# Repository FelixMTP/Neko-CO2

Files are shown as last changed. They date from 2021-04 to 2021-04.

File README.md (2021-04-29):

# Neko+++

Le Neko+++ est un capteur de CO2 avec buzzer et calibration manuelle avec ou sans batterie

auquel j'ai ajouté :
- un buzzer qui sonne un certain nombre de fois.
- une batterie rechargeable
- une fonction de calibration manuelle en extérieur (plus simple) et d’une fonction de calibration manuelle à partir d’un capteur étalonné (plus compliqué)
- trois interrupteurs : pour allumer et éteindre le capteur, pour activer et désactiver le buzzer, pour lancer la calibration

Il est basé sur un mélange :
- du modèle Neko, qui a servi de base : http://lafabrique.centralesupelec.fr/projetco2/#autres
- du modèle Koneko : https://developer.sensirion.com/tutorials/create-your-own-co2-monitor/ et http://lafabrique.centralesupelec.fr/projetco2/#autres
Pour le relevé de mesures du capteur sensirion SCD30, la communication des mesures par Bluetooth et l'application mobile
- du modèle CO2 Ampel : https://github.com/make-IoT/CO2-Ampel/blob/main/CO2-Ampel-DIY-Octopus-SCD30-WEB-AP-CAL.ino
Pour la calibration à une valeur donnée par wifi et la calibration sur l'air extérieur

Fournitures utilisées pour ce modèle (les liens sont indicatifs, les composants identiques ou équivalents peuvent s’acheter ailleurs) :
- 1 Carte ESP32 : https://www.amazon.fr/gp/product/B074RGW2VQ/ (les autres ESP32 sont possible, il faudra juste adapter les paramètres dans l’IDE arduino)
- 2 ou 3 Interrupteurs (2 pour le modèle sans batterie, 3 pour le modèle avec batterie) : https://www.amazon.fr/gp/product/B00O9YQB88/ (d’autres interrupteurs sont possibles aussi mais il faudra peut-être adapter de fichier STL du couvercle)
- 4 Leds : Rouge, jaune, vert, bleu de 20mA
- 4 Résistance 100 ohms
- 1 Capteur : Sensirion SCD30
- 1 Convertisseur d’alimentation (seulement pour le modèle avec batterie) : https://www.amazon.fr/gp/product/B07MY3NZ18
- 1 Module de charge de batterie 18650 (seulement pour le modèle avec batterie) : https://www.amazon.fr/gp/product/B0798M12N8
- 1 Batterie 18650 (seulement pour le modèle avec batterie) : https://www.amazon.fr/gp/product/B08CC5P4HN/
- 1 Support pour batterie (seulement pour le modèle avec batterie) : https://www.amazon.fr/gp/product/B08CY56M98/

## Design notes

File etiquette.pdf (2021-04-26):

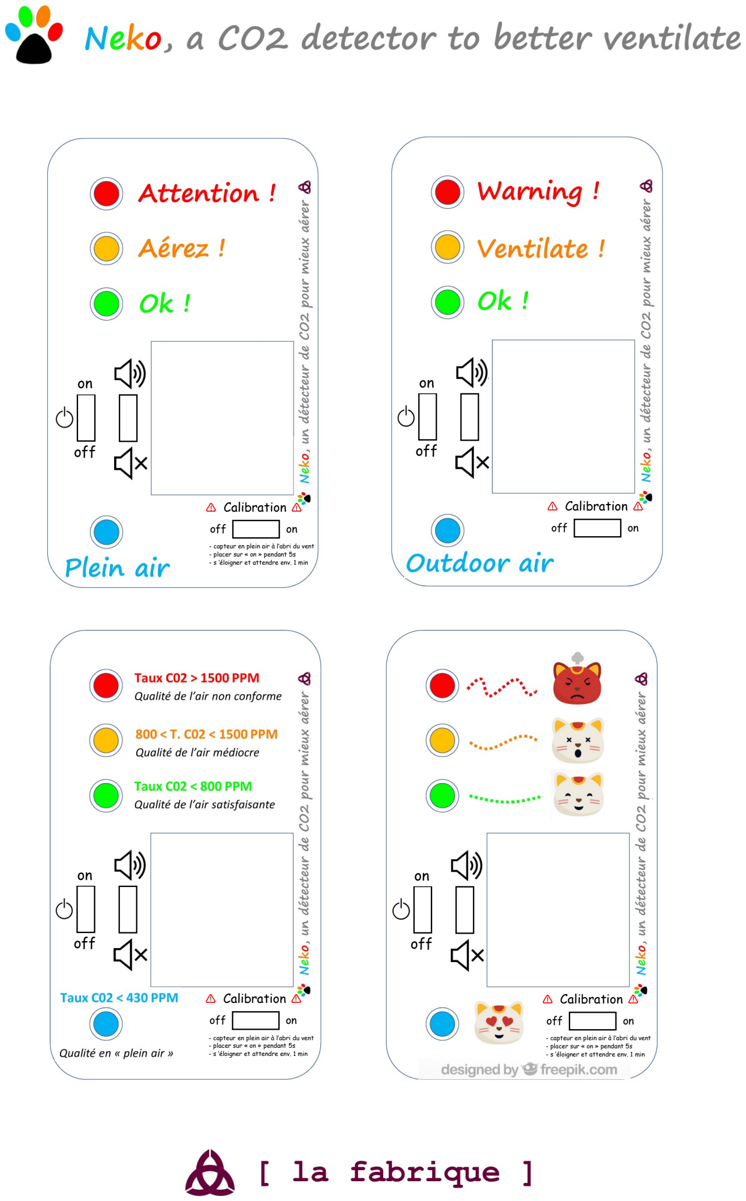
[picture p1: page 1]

# off

on

off | on
- capteur en plein air à l’abri du vent
- placer sur « on » pendant 5s
- s ‘éloigner et attendre env. 1 min

# ! Calibration !

# off

on

off | on
- capteur en plein air à l’abri du vent
- placer sur « on » pendant 5s
- s ‘éloigner et attendre env. 1 min

# ! Calibration !

# off

on

off | on
! | Calibration !

# off

on

off | on
- capteur en plein air à l’abri du vent
- placer sur « on » pendant 5s
- s ‘éloigner et attendre env. 1 min
! | Calibration | !

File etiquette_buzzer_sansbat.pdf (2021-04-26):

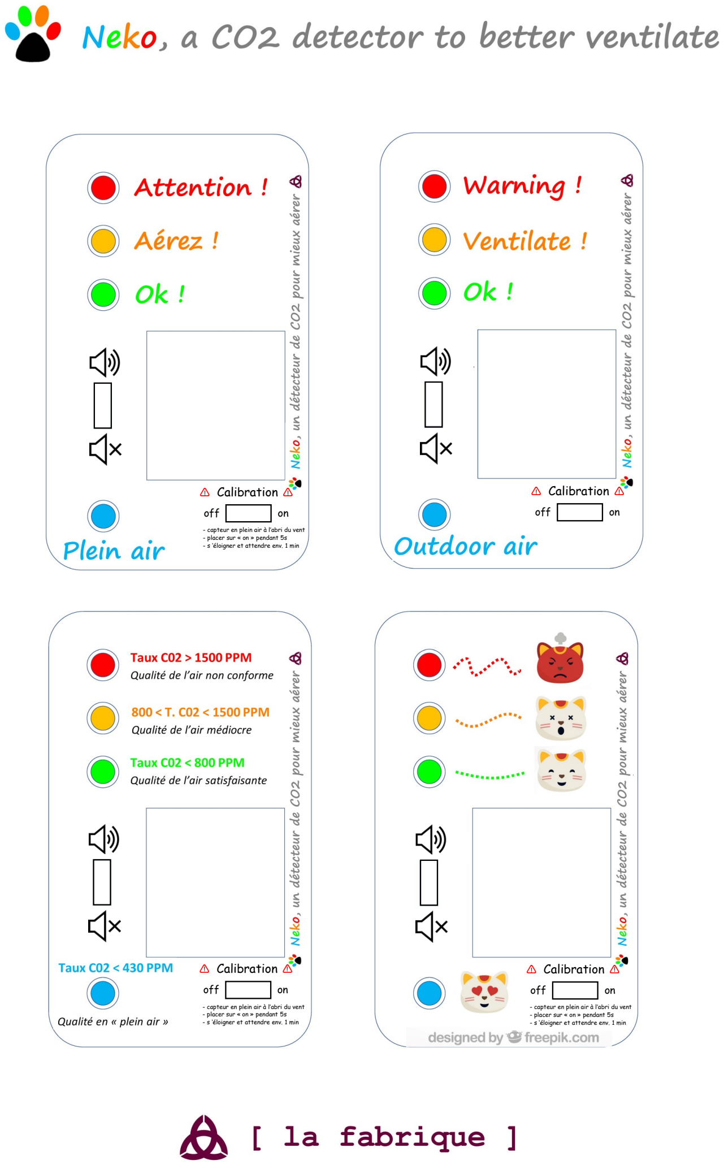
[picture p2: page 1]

off | on
- capteur en plein air à l’abri du vent
- placer sur « on » pendant 5s
- s ‘éloigner et attendre env. 1 min
! | Calibration !
off | on
- capteur en plein air à l’abri du vent
- placer sur « on » pendant 5s
- s ‘éloigner et attendre env. 1 min
! | Calibration !
off | on
! | Calibration !
off | on
- capteur en plein air à l’abri du vent
- placer sur « on » pendant 5s
- s ‘éloigner et attendre env. | 1 min
! | Calibration | !

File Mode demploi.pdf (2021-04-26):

# Capteur de CO2 Neko+++

Le taux de CO2 en extérieur est d’environ 400 ppm.
La mesure du taux de CO2 dans les lieux clos donne ainsi une indication de la quantité d’air qui a été expiré par les personnes présentes dans la pièce, donc une indication de la concentration en aérosols et du risque de transmission du Covid dans ce lieu.
Pour être utilisé, ce capteur doit être calibré à partir de l’air extérieur. Cette calibration peut être renouvelée régulièrement.

### 1) Calibration simple :

Précautions : éviter la calibration lorsqu’il y a beaucoup de vent car le vent perturbe la mesure donc la calibration. Si nécessaire, placer le capteur à l’abri entre des objets ou une boite mais ne pas la fermer complètement.
Þ Placer le capteur en extérieur, loin de tout source de CO2 (donc loin d’une fenêtre, d’une évacuation d’air, d’une cheminée, d’animaux ou de personnes, etc) pendant quelques minutes
Þ Positionner le bouton de calibration sur ON jusqu’à ce que les LED de couleur s’éteignent puis repositionnez le bouton de calibration sur OFF et s’éloigner rapidement de plusieurs mètres
Þ Laisser le capteur effectuer sa calibration jusqu’à ce que l’une des LED (normalement la bleue) se rallume. Cette opération peut prendre plusieurs minutes.
Après quelques temps d’utilisation en intérieur, il est conseillé de tester régulièrement la calibration en plaçant le capteur en extérieur et vérifier que la moyenne des mesures se situe autour de 400 ppm.

### 2) Utilisation:

Þ Placer le capteur dans la pièce à mi-hauteur. Il ne doit pas être placé à coté d’une fenêtre, ni juste à côté d’une personne car cela fausserait les mesures.
Þ | Positionner le bouton | sur ON
Þ | Positionner le bouton du buzzer : | si le buzzer doit sonner lorsque le taux devient supérieur à 1500 ppm ou | s’il ne doit pas sonner.

### 3) Mesure :

Þ Mesure simple : Les LEDS s’allument en fonction du taux de CO2 mesuré.
- Led bleue : le lieu est très bien ventilé car la qualité de l’air est semblable à l’air extérieur
- Led verte : Le lieu est correctement ventilé
- Led orange/jaune : Le lieu n’est pas assez ventilé, il faudrait donc ouvrir (ou ouvrir davantage) les fenêtres.
- Led rouge : le lieu n’est pas ou trop peu ventilé et la qualité de l’air n’est pas conforme, il faut ouvrir les fenêtres.

Þ Mesure chiffrée :
Si vous souhaitez obtenir le taux de CO2 mesuré par le capteur, vous pouvez installer l’application
mobile Sensirion MyAmbience à partir du QR-Code ou les liens suivants :
- Pour Android : https://play.google.com/store/apps/details?id=com.sensirion.myam
- Pour iOS : https://apps.apple.com/ch/app/sensirion-myambience-co2/id1529131572 N’oubliez pas d’activer le Bluetooth de votre appareil.
Une fois installée, l’application se connecte au capteur par Bluetooth et affiche :

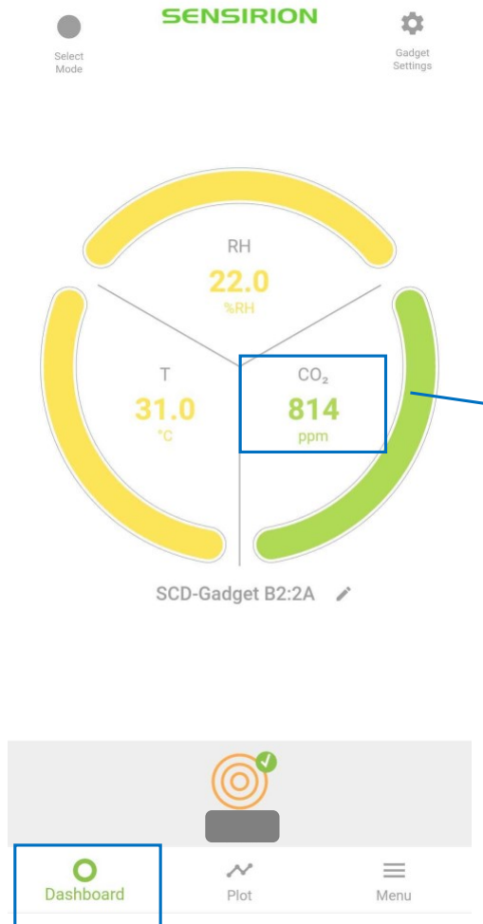
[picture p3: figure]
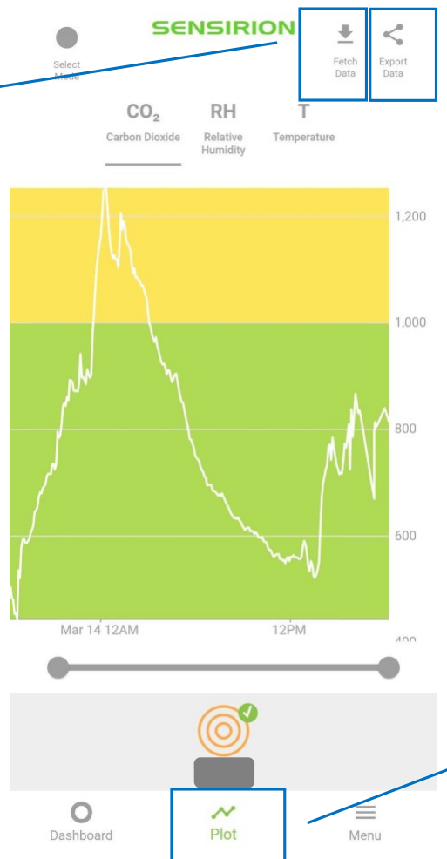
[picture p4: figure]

Taux de CO2.
Attention, les plages de
couleurs dans l’appli ne
correspondent pas aux plages de couleurs pour limiter les risques de transmission du covid

Onglet Dashboard :
Affiche la mesure
instantanée

Exporter les données :
Permet de récupérer les
mesures dans un tableau qui peut s’ouvrir avec un tableur

Onglet Plot :
Affiche la courbe des mesures. Attention, pour que la courbe soit complète, il faut télécharger les données du capteur

Acquérir les données :
Permet de récupérer les
mesures du capteur pour que le graphique soit complet. Attention : ça prend très
longtemps !
Android : | Apple :

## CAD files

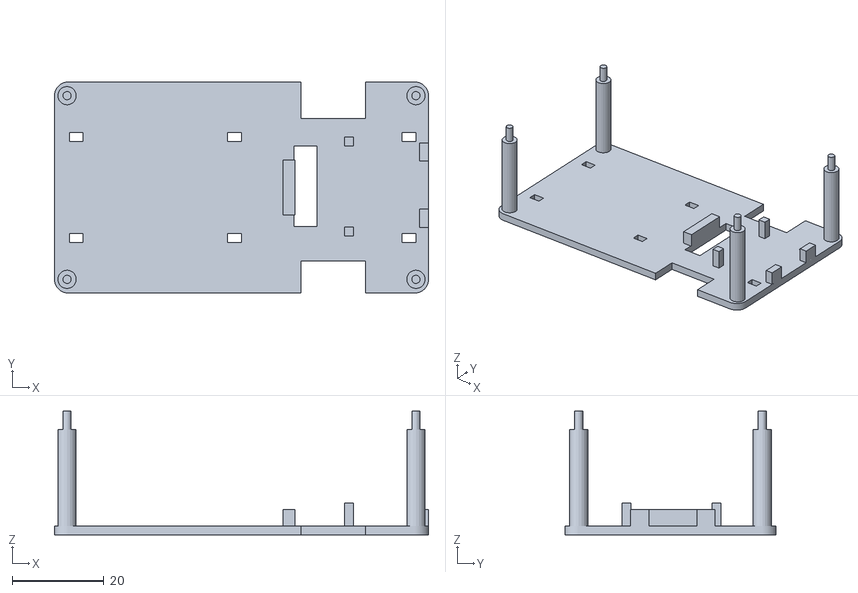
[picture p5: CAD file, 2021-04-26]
Boitier/PCB2.stl
81.5 x 46.0 x 27.0

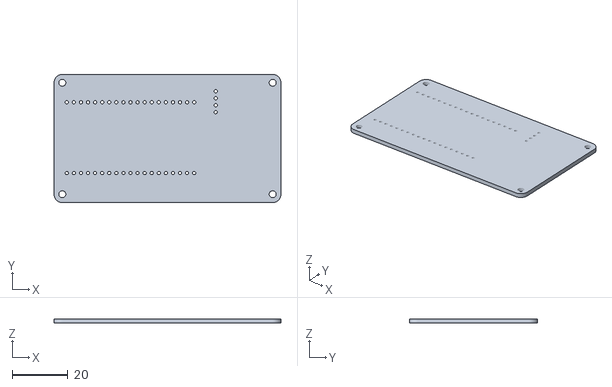
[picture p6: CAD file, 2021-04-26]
Boitier/PCB1.stl
81.5 x 46.0 x 1.60

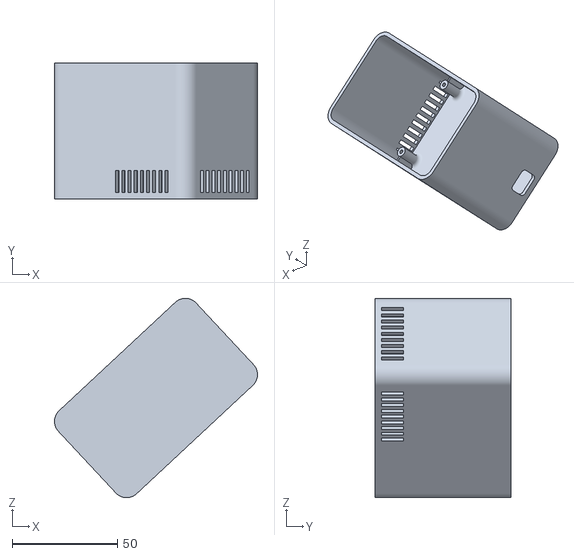
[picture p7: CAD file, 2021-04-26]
Boitier/boitier_sans_batterie.stl
96.5 x 64.6 x 94.7

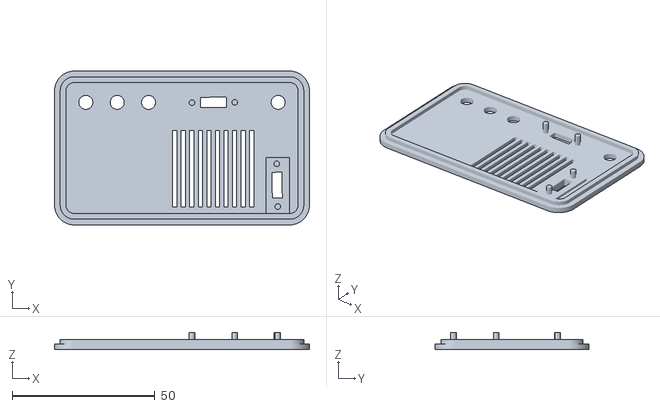
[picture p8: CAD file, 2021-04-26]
Boitier/facade_2boutons.stl
89.5 x 54.0 x 6.00

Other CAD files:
Boitier/boitier_batterie.stl
Boitier/facade_3boutons.stl

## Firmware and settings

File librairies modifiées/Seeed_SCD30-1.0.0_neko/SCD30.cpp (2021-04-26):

/*
    A library for Grove -

    Copyright (c) 2018 seeed technology co., ltd.
    Author      : Wayen Weng
    Create Time : November 2018
    Change Log  :

    The MIT License (MIT)

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
    THE SOFTWARE IS PROVIDED "AS IS", WITHOUT WARRANTY OF ANY KIND, EXPRESS OR
    IMPLIED, INCLUDING BUT NOT LIMITED TO THE WARRANTIES OF MERCHANTABILITY,
    FITNESS FOR A PARTICULAR PURPOSE AND NONINFRINGEMENT. IN NO EVENT SHALL THE
    AUTHORS OR COPYRIGHT HOLDERS BE LIABLE FOR ANY CLAIM, DAMAGES OR OTHER
    LIABILITY, WHETHER IN AN ACTION OF CONTRACT, TORT OR OTHERWISE, ARISING FROM,
    OUT OF OR IN CONNECTION WITH THE SOFTWARE OR THE USE OR OTHER DEALINGS IN
    THE SOFTWARE.
*/

#include "SCD30.h"

SCD30::SCD30(void) {
    devAddr = SCD30_I2C_ADDRESS;
}

void SCD30::initialize(void) {
    //Set temperature offset。
    //setTemperatureOffset(0);

    setMeasurementInterval(2); // 2 seconds between measurements
    startPeriodicMeasurment(); // start periodic measuments

    //setAutoSelfCalibration(true); // Enable auto-self-calibration
}


void SCD30::setTemperatureOffset(uint16_t offset) {
    writeCommandWithArguments(SCD30_SET_TEMP_OFFSET, offset);
}

bool SCD30::isAvailable(void) {
    return readRegister(SCD30_GET_DATA_READY);
}

void SCD30::setAutoSelfCalibration(bool enable) {
    if (enable) {
        writeCommandWithArguments(SCD30_AUTOMATIC_SELF_CALIBRATION, 1);    //Activate continuous ASC
    } else {
        writeCommandWithArguments(SCD30_AUTOMATIC_SELF_CALIBRATION, 0);    //Deactivate continuous ASC
    }
}

//Set the forced recalibration factor. See 1.3.7.
//The reference CO2 concentration has to be within the range 400 ppm ≤ cref(CO2) ≤ 2000 ppm.
void SCD30::setForcedRecalibrationFactor(uint16_t concentration)
{
  if (concentration > 400 || concentration < 2000)
	writeCommandWithArguments(SCD30_SET_FORCED_RECALIBRATION_FACTOR, concentration);
  }

void SCD30::setMeasurementInterval(uint16_t interval) {
    writeCommandWithArguments(SCD30_SET_MEASUREMENT_INTERVAL, interval);
}

void SCD30::startPeriodicMeasurment(void) {
    writeCommandWithArguments(SCD30_CONTINUOUS_MEASUREMENT, 0x0000);
}

void SCD30::stopMeasurement(void) {
    writeCommand(SCD30_STOP_MEASUREMENT);
}

void SCD30::getCarbonDioxideConcentration(float* result) {
    uint8_t buf[18] = { 0 };
    uint32_t co2U32 = 0;
    uint32_t tempU32 = 0;
    uint32_t humU32 = 0;
    float co2Concentration = 0;
    float temperature = 0;
    float humidity = 0;

    writeCommand(SCD30_READ_MEASUREMENT);
    readBuffer(buf, 18);

    co2U32 = (uint32_t)((((uint32_t)buf[0]) << 24) | (((uint32_t)buf[1]) << 16) |
                        (((uint32_t)buf[3]) << 8) | ((uint32_t)buf[4]));

    tempU32 = (uint32_t)((((uint32_t)buf[6]) << 24) | (((uint32_t)buf[7]) << 16) |
                         (((uint32_t)buf[9]) << 8) | ((uint32_t)buf[10]));

    humU32 = (uint32_t)((((uint32_t)buf[12]) << 24) | (((uint32_t)buf[13]) << 16) |
                        (((uint32_t)buf[15]) << 8) | ((uint32_t)buf[16]));

    memcpy(&result[0], &co2U32, sizeof(co2Concentration));
    memcpy(&result[1], &tempU32, sizeof(temperature));
    memcpy(&result[2], &humU32, sizeof(humidity));

}

void SCD30::writeCommand(uint16_t command) {
    Wire.beginTransmission(devAddr);
    Wire.write(command >> 8); // MSB
    Wire.write(command & 0xff); // LSB
    Wire.endTransmission();
}

void SCD30::writeCommandWithArguments(uint16_t command, uint16_t arguments) {
    uint8_t checkSum, buf[5] = { 0 };

    buf[0] = command >> 8;
    buf[1] = command & 0xff;
    buf[2] = arguments >> 8;
    buf[3] = arguments & 0xff;
    checkSum = calculateCrc(&buf[2], 2);
    buf[4] = checkSum;

    writeBuffer(buf, 5);
}

uint16_t SCD30::readRegister(uint16_t address) {
    uint8_t buf[2] = { 0 };

    writeCommand(address);
    readBuffer(buf, 2);

    return ((((uint16_t)buf[0]) << 8) | buf[1]);
}

void SCD30::writeBuffer(uint8_t* data, uint8_t len) {
    Wire.beginTransmission(devAddr);
    Wire.write(data, len);
    Wire.endTransmission();
}

void SCD30::readBuffer(uint8_t* data, uint8_t len) {
    uint8_t i = 0;

    Wire.requestFrom(devAddr, len);
    while (Wire.available()) {
        data[i ++] = Wire.read();
    }
}

uint8_t SCD30::calculateCrc(uint8_t data[], uint8_t len) {
    uint8_t bit, byteCtr, crc = 0xff;

    // calculates 8-Bit checksum with given polynomial
    for (byteCtr = 0; byteCtr < len; byteCtr ++) {
        crc ^= (data[byteCtr]);

        for (bit = 8; bit > 0; -- bit) {
            if (crc & 0x80) {
                crc = (crc << 1) ^ SCD30_POLYNOMIAL;
            } else {
                crc = (crc << 1);
            }
        }
    }

    return crc;
}

SCD30 scd30;

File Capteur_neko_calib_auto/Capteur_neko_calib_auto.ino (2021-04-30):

#include "esp_timer.h"
#include <Wire.h>
#include "SCD30.h"
#include "Sensirion_GadgetBle_Lib.h"
#include <EasyBuzzer.h>

// Paramètres à modifier selon le montage électronique
#define SDA_pin 26      // Define the SDA pin used for the SCD30
#define SCL_pin 27      // Define the SCL pin used for the SCD30
int ledR = 19;          // Pin de la led rouge
int ledO = 18;          // Pin de la led orange ou jaune
int ledV = 5;           // Pin de la led verte
int ledB = 17;          // Pin de la led bleue
int pin = 25;           // Pin du Buzzer
int pin_calib = 21;     // Pin de l'interrupteur servant à la calibration 

// Parametres du BUZZER
int nbip = 3;       // Modifier ici le nombre de bip souhaités
int hz = 440;       // Définir ici la fréquence du son souhaité
int duree = 1000;   // Définir ici la durée du bip souhaitée (pas garanti que ça fonctionne en cas de modification)

// Paramètres de la mesure du capteur
int mesure_moyenne_basee_sur = 3; // Fixe la mesure à la moyenne de x mesures pour éviter les fluctuations. Mettre 1 effectuera une mesure non moyennée

// Paramètres des plages de taux de CO2  
float limite_orange = 800;    // Passe les leds et la figure en orange au dela de ce taux
float limite_rouge = 1500;    // Passe les leds et la figure en rouge au dela de ce taux

// Paramètres de calibation manuelle
int test_calib = 10;           // Teste la calibration sur la moyenne de 10 mesures. La valeur moyenne obtenue doit être comprise entre la fourchette haute et la fourchette basse
int fourchette_basse = 390;    // Valeur la plus basse acceptable au test de calibration
int fourchette_haute = 420;    // Valeur la plus hautte acceptable au test de calibration
String cal_passwort = "calib"; // Mot de passe protégeant la calibration
String cal_message  = "";      // Message de calibration
int autocalib = 0;             // Mettre à 1 si vous voulez utiliser la fonction d'autocalibration INTERNE AU CAPTEUR Sensirion scd30 ou 0 si vous voulez utiliser la calibration à taux forcé de ce programme
int val_calib = 400;           // Mettre ici le taux de CO2 servant à la calibration à taux forcé

// Variables à ne pas modifier
int compteur = 0;       // Compteur à ne pas modifier, sert à compter le nombre de bip
static int64_t lastMmntTime = 0;
static int startCheckingAfterUs = 1900000;
GadgetBle gadgetBle = GadgetBle(GadgetBle::DataType::T_RH_CO2_ALT);
float result[3] = {0};
int calibration = 0;    // Marqueur qui indique si on doit effectuer une calibration
  
// Fonction de calibration manuelle
SCD30 airSensorSCD30; // Objekt SDC30 Umweltsensor
void calibrationCO2(int valeur){ // Fonction de calibration
  airSensorSCD30.setForcedRecalibrationFactor(valeur);  // Calibration selon la valeur entrée en paramètre 
  delay(20000);
}

void setup() {
  Serial.begin(115200);
  pinMode(ledR, OUTPUT);
  pinMode(ledO, OUTPUT);
  pinMode(ledV, OUTPUT);
  pinMode(ledB, OUTPUT);
  pinMode(pin_calib, INPUT_PULLDOWN);
  delay(100);
  EasyBuzzer.setPin(pin);
  
  // Initialisation du SCD30
  gadgetBle.begin();
  Serial.print("Identifiant du capteur = ");
  Serial.println(gadgetBle.getDeviceIdString());

  // Initialize the SCD30 driver
  Wire.begin(SDA_pin, SCL_pin);
  
  scd30.initialize();
  scd30.setAutoSelfCalibration(autocalib); // Définit l'autocalibration selon le choix indiqué plus haut
}

void loop() {
  // remise à zéro des variables servant au calcul de la moyenne
  int co2 = 0;
  int temp = 0;
  int hum = 0;
  
  // Controle de l'état du bouton de calibration
  int state_calib = digitalRead(pin_calib);
  Serial.print("calibration : "); Serial.println(state_calib);
  if (state_calib == HIGH) {
    calibration = 1;  
  }
  
  // Si le bouton de calibration est sur ON ou si le test de calibration précédent n'était pas correct, appel de la fonction de calibration au taux de base
  if (calibration == 1) {
    digitalWrite(ledB,LOW);    // on éteint toutes les leds. Elles se rallumeront lors la calibration sera complète.
    digitalWrite(ledV,LOW);
    digitalWrite(ledO,LOW);
    digitalWrite(ledR,LOW);
    Serial.print("Calibration en cours à "); Serial.print(val_calib); Serial.println(" ppm...");
    delay(20000);              // Délai pour laisser le temps de s'éloigner du capteur
    calibrationCO2(val_calib); // Calibration à taux fixé
    Serial.println("Calibration effectuée !");
    Serial.println("Test de calibration...");
    // remise à zéro des variables servant au calcul de la moyenne
    int co2 = 0;
    //Mesures répétées
    for (int i=0; i<test_calib; i++) {
      scd30.getCarbonDioxideConcentration(result);
      Serial.print("CO2[ppm]:"); Serial.println(result[0]);
      delay(2000);
      if (result[0]<10000) {      // Elimination des mesures erronées
        co2 = co2 + result[0];
      } else {
        i--;
      }
    }
    // Calcul de la moyenne
    co2= co2/test_calib;
    Serial.print("Calibration moyenne basée sur ");
    Serial.print(test_calib);
    Serial.println(" mesures.");
    Serial.print("CO2[ppm] moyenne :");
    Serial.println(co2);
    if (co2 > fourchette_basse && co2 < fourchette_haute) {
      calibration = 0;
      Serial.println("Calibration effectuée et testée avec succes !");
      } else {
      Serial.println("La calibration n'est pas correcte.");
    }
    delay(1000);
    }
    delay(2000);
  
  // Mesure du CO2, de la température et du taux d'humidité
  if (esp_timer_get_time() - lastMmntTime >= startCheckingAfterUs && calibration ==0) {
    if (scd30.isAvailable()) {
      //Mesures répétées
      for (int i=0; i<mesure_moyenne_basee_sur; i++) {
        scd30.getCarbonDioxideConcentration(result);
        Serial.print("CO2[ppm]:");
        Serial.print(result[0]);
        Serial.print("\t");
        Serial.print("Temperature[℃]:");
        Serial.print(result[1]);
        Serial.print("\t");
        Serial.print("Humidity[%]:");
        Serial.print(result[2]);
        Serial.println("\t");
        delay(3000);
            co2 = co2 + result[0];
        temp = temp + result[1];
        hum = hum + result[2];
      }
      
      // Calcul de la moyenne
      co2= co2/mesure_moyenne_basee_sur;
      temp= temp/mesure_moyenne_basee_sur;
      hum= hum/mesure_moyenne_basee_sur;
  
      Serial.print("Moyenne basée sur:");
      Serial.print(mesure_moyenne_basee_sur);
      Serial.print("\t");
      Serial.print("CO2[ppm] moyenne :");
      Serial.print(co2);
      Serial.print("\t");
      Serial.print("Temperature[℃] moyenne :");
      Serial.print(temp);
      Serial.print("\t");
      Serial.print("Humidity[%] moyenne :");
      Serial.print(hum);
      Serial.println("\t");
      if (co2 > 400 && co2 < 100000) { // Si la moyenne est en dehors des valeurs plausibles, c'est qu'il y a eu une erreur de mesure
        gadgetBle.writeCO2(co2);
        gadgetBle.writeTemperature(temp);
        gadgetBle.writeHumidity(hum);
        gadgetBle.commit();
        lastMmntTime = esp_timer_get_time();
        // Provide the sensor values for Tools -> Serial Monitor or Serial Plotter
        EasyBuzzer.update();
        if (result[0] < 430){       // S'il y a moins de 430 ppm de CO2
          digitalWrite(ledB,HIGH);    // on allume la led bleue
          digitalWrite(ledV,LOW);
          digitalWrite(ledO,LOW);
          digitalWrite(ledR,LOW);
          compteur =0;                // on remet à zéro le compteur pour que le buzzer puisse sonner à nouveau
        }
        else if (result[0] < 800 && result[0] >= 430){     // S'il y a entre 430 et 800 ppm de CO2
          digitalWrite(ledB,LOW);
          digitalWrite(ledV,HIGH);                           // on allume la led verte
          digitalWrite(ledO,LOW);
          digitalWrite(ledR,LOW);
          compteur =0;                                       // on remet à zéro le compteur pour que le buzzer puisse sonner à nouveau
        }
        else if (result[0] >= 800 && result[0] < 1500){    // S'il y a entre 800 et 1500 ppm de CO2
          digitalWrite(ledB,LOW);
          digitalWrite(ledO,HIGH);                           // on allume la led orange ou jaune
          digitalWrite(ledV,LOW);
          digitalWrite(ledR,LOW);
          // Déplacer ici les lignes correspondant à la sonnerie du buzzer si besoin qu'il sonne dès la limite de 800ppm
    
          // Fin des lignes à déplacer
          // + Commenter la ligne suivante si le buzzer doit sonner dès la limite de 800ppm
          compteur =0; // on remet à zéro le compteur pour que le buzzer puisse sonner à nouveau
        }
        else if (result[0] >= 1500){    // Si on dépasse les 1500 ppm de CO2
          digitalWrite(ledB,LOW);
          digitalWrite(ledR,HIGH);        // on allume la led rouge
          digitalWrite(ledO,LOW);
          digitalWrite(ledV,LOW);
                      // On fait sonner le buzzer

          // Déplacer ces lignes plus haut si le buzzer doit sonner lors du passage de la limite de 800ppm
          if (compteur < nbip) {
            EasyBuzzer.singleBeep(hz, duree);
            compteur = compteur+1;
            delay(1000);
            EasyBuzzer.stopBeep();
          // Fin des lignes à déplacer
          }
        }
      }
    }
    gadgetBle.handleEvents();
    delay(3000);
  }
}
